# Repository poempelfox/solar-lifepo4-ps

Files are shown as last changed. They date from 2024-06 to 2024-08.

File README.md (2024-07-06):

# Solar-LiFePO4 power-supply module

## Intro

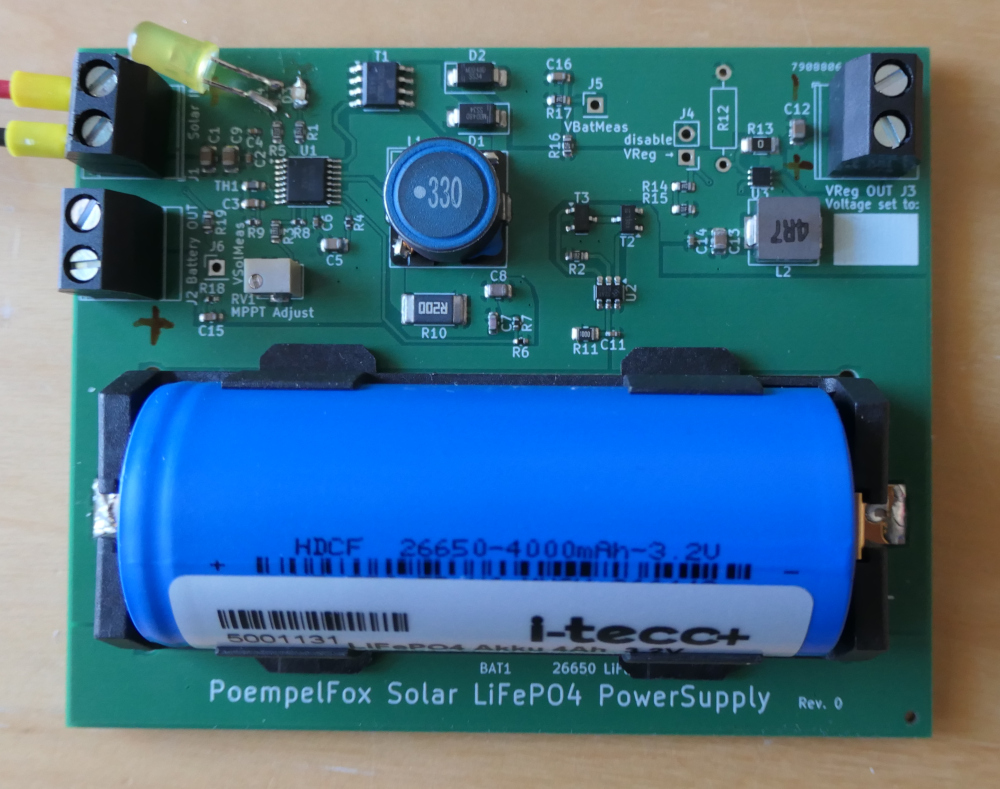
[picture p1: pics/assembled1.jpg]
picture showing the first revision of the board in this project. A printed circuit board with many components mounted on, including a very big battery covering almost the bottom half of the picture.


The goal of this project is to build a power-supply
module with a standard 26650 LiFePO4 battery that can
be powered from a small solar panel and will take
care of all the handling of the battery, including
protection, for you.
The battery is put into a battery holder that is
directly on the board.

Essentially, this is trying to build something
very similiar to Waveshares "Solar Power Manager",
just using LiFePO4 instead of Li-Ion. The
downside is the smaller energy density. The upside
is that LiFePO4 is much much more stable and simply
can not spontanously burst into flames.

I would have preferred to not design this myself,
because I'm really out of my depth here. However,
I was completely unable to find something ready-made
to buy, and even my search for (open-source-)projects
that had already built something like that proved
fruitless. Of course, after I was two-thirds finished,
I accidently found the
[LiFePO4 Solar Charger by Stefan Wagner](https://github.com/wagiminator/Power-Boards/blob/master/Solar_Charger/readme.md)
that would have been almost exactly what I was looking
for, but by then it was too late.

During construction,
[a blog entry by Malte Poeggel and his design files](https://www.maltepoeggel.de/?site=solar-mppt-cn3722&lang=en)
was a great inspiration, because it uses the same
main charge controller (CN3722) and so I had a known-working
design to start from.

## Features

Input is meant to be a 12V solar panel. Maximum input
voltage for the circuit is 25V, so the solar panel
voltage without any load should be fine.

The board has a slot for a standard 26650 LiFePO4
flat top unprotected battery. The protection circuit
(HY2112) is on the board and protects against
short circuits, overcharge, and deep discharge.
There is also protection against charging below
0°C (which can damage LiFePO4 batteries), but that
is done by the main CN3722 charge controller which has
a Thermistor connected for that purpose. Note that
because the Thermistor is on the board and not
directly attached to the battery, this may be
insufficient for some use cases where large
temperature differences between board and battery
can occour.

Charge current is capped at 1A.

There is a regulated 5V output through an ultra-
efficient MAX17224 boost converter. Output voltage can
be reconfigured to between 3.4 - 5V by removing and
soldering in another resistor. However, because this
is a boost converter, you cannot (reliably) go below
3.4V - the minimum voltage is (battery voltage - 0.2V).
You should be able to pull around 400 mA at 5V or
600 mA at 3.4V out of this - although if you pull this
much current permanently, you'll not last long
with such a small battery.

You can also get the 3.0V - 3.6V output coming from
the battery directly, but that is of course completely
unregulated, and will fluctuate as the battery charges
and discharges. This output is behind the battery
protection circuit, so protected against deep
discharge.

There is a jumper for disabling the boost converter
completely if you don't need the regulated output.
It's also possible to connect a microcontroller to
that jumper and thereby enable/disable the regulated
output in software. A nifty feature of the MAX17224
is that when it is disabled, it completely disconnects
its output, meaning it doesn't care at all if you
feed voltage into that.

Finally, there are two voltage dividers on the board,
with an output that is intended to be connected to
an ADC pin of a microcontroller. A 10 MOhm / 1 MOhm
divider to measure the voltage coming from the solar
panel, and a 10 MOhm / 10 MOhm divider for the battery
voltage. These were selected so that the output
conveniently matches the range of your standard ESP32.

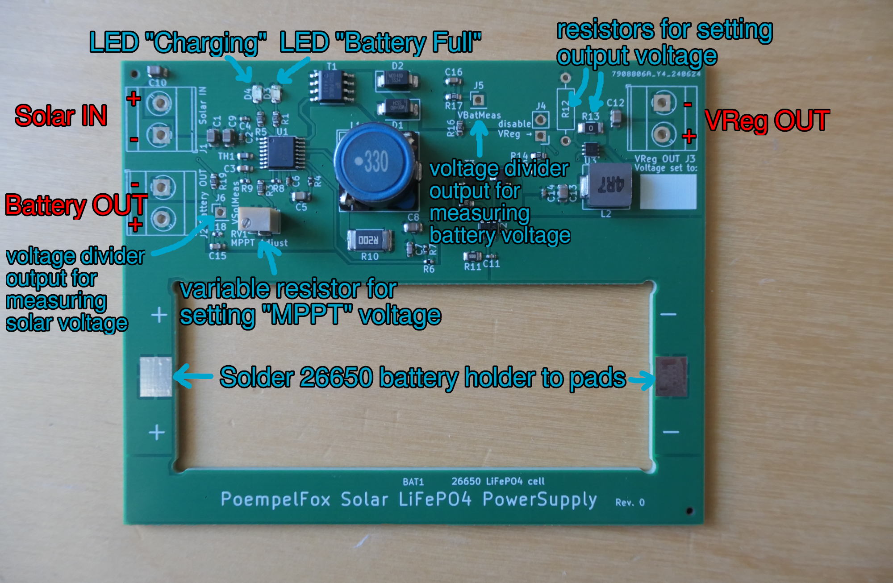
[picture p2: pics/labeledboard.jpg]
a picture showing the printed circuit board, with labels showing what needs to be connected where.


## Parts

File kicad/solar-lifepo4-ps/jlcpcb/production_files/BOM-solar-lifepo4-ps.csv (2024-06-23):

Comment | Designator | Footprint | LCSC
C1 | 22uF | C_0805_2012Metric | C45783 | 4372673 | 0 | 0
C10 | 22uF | C_0805_2012Metric | C45783 | 4372673 | 0 | 0
C11 | 100nF | C_0402_1005Metric | C307331 | 6856879 | 0 | 0
C12 | 22uF | C_0805_2012Metric | C45783 | 4372673 | 0 | 0
C13 | 22uF | C_0805_2012Metric | C45783 | 4372673 | 0 | 0
C14 | 100nF | C_0402_1005Metric | C307331 | 6856879 | 0 | 0
C15 | 1nF | C_0603_1608Metric | C1588 | 6040604 | 0 | 0
C16 | 1nF | C_0603_1608Metric | C1588 | 6040604 | 0 | 0
C2 | 100nF | C_0402_1005Metric | C307331 | 6856879 | 0 | 0
C3 | 470pF | C_0603_1608Metric | C1620 | 841712 | 0 | 0
C4 | 100nF | C_0402_1005Metric | C307331 | 6856879 | 0 | 0
C5 | 220nF | C_0805_2012Metric | C5378 | 425353 | 0 | 0
C6 | 100nF | C_0402_1005Metric | C307331 | 6856879 | 0 | 0
C7 | 18pF | C_0603_1608Metric | C1647 | 224429 | 0 | 0
C8 | 10uF | C_0805_2012Metric | C15850 | 2210217 | 0 | 0
C9 | 22uF | C_0805_2012Metric | C45783 | 4372673 | 0 | 0
D1 | SS34 | D_SMA | C8678 | 997276 | 0 | 0
D2 | SS34 | D_SMA | C8678 | 997276 | 0 | 0
D3 | LED green | R_0805_2012Metric | C2297 | 1323534 | 0 | 0
D4 | LED yellow | R_0805_2012Metric | C2296 | 258402 | 0 | 0
L1 | 33uH | L_TDK_SLF12575 | C87568 | 2465 | 0 | 0
L2 | 4.7uH | L_Sunlord_MWSA0603S | C408447 | 60265 | 0 | 0
R1 | 2.4k | R_0603_1608Metric | C22940 | 702809 | 0 | 0
R10 | 200m | R_2512_6332Metric | C5375488 | 8341 | 0 | 0
R11 | 100 | R_0805_2012Metric | C17408 | 6372890 | 0 | 0
R13 | VoltageSelB | R_1206_3216Metric | C17888 | 8173888 | 0 | 0
R14 | 10M | R_0603_1608Metric | C7250 | 225082 | 0 | 0
R15 | 10M | R_0603_1608Metric | C7250 | 225082 | 0 | 0
R16 | 10M | R_0603_1608Metric | C7250 | 225082 | 0 | 0
R17 | 10M | R_0603_1608Metric | C7250 | 225082 | 0 | 0
R18 | 1M | R_0402_1005Metric | C26083 | 2594408 | 0 | 0
R19 | 10M | R_0603_1608Metric | C7250 | 225082 | 0 | 0
R2 | 1.8k | R_0603_1608Metric | C4177 | 435015 | 0 | 0
R3 | 3.9k | R_0603_1608Metric | C23018 | 817563 | 0 | 0
R4 | 120 | R_0402_1005Metric | C25079 | 547006 | 0 | 0
R5 | 2.4k | R_0603_1608Metric | C22940 | 702809 | 0 | 0
R6 | 48.7k | R_0402_1005Metric | C103068 | 47167 | 0 | 0
R7 | 23.7k | R_0402_1005Metric | C82134 | 14674 | 0 | 0
R8 | 100k | R_0402_1005Metric | C25741 | 4991595 | 0 | 0
R9 | 1M | R_0402_1005Metric | C26083 | 2594408 | 0 | 0
RV1 | Poti 10k | Potentiometer_Bourns_3224W_Vertical | C81348 | 6722 | 0 | 0
T1 | SI4435DY | SOP-8_3.9x4.9mm_P1.27mm | C4355022 | 19004 | 0 | 0
T2 | AO3400A | SOT-23 | C20917 | 628525 | 0 | 0
T3 | AO3400A | SOT-23 | C20917 | 628525 | 0 | 0
TH1 | Thermistor NTC 10k | R_0603_1608Metric | C13564 | 438964 | 0 | 0
U1 | CN3722 | TSSOP-16_4.4x5mm_P0.65mm | C77905 | 5126 | 0 | 0
U2 | HY2112 | SOT-23-6 | C168763 | 5680 | 0 | 0
U3 | MAX17224ELT+T | UDFN-6_L2.0-W2.0-P0.65-BL-1 | C2683469 | 139 | 0 | 0

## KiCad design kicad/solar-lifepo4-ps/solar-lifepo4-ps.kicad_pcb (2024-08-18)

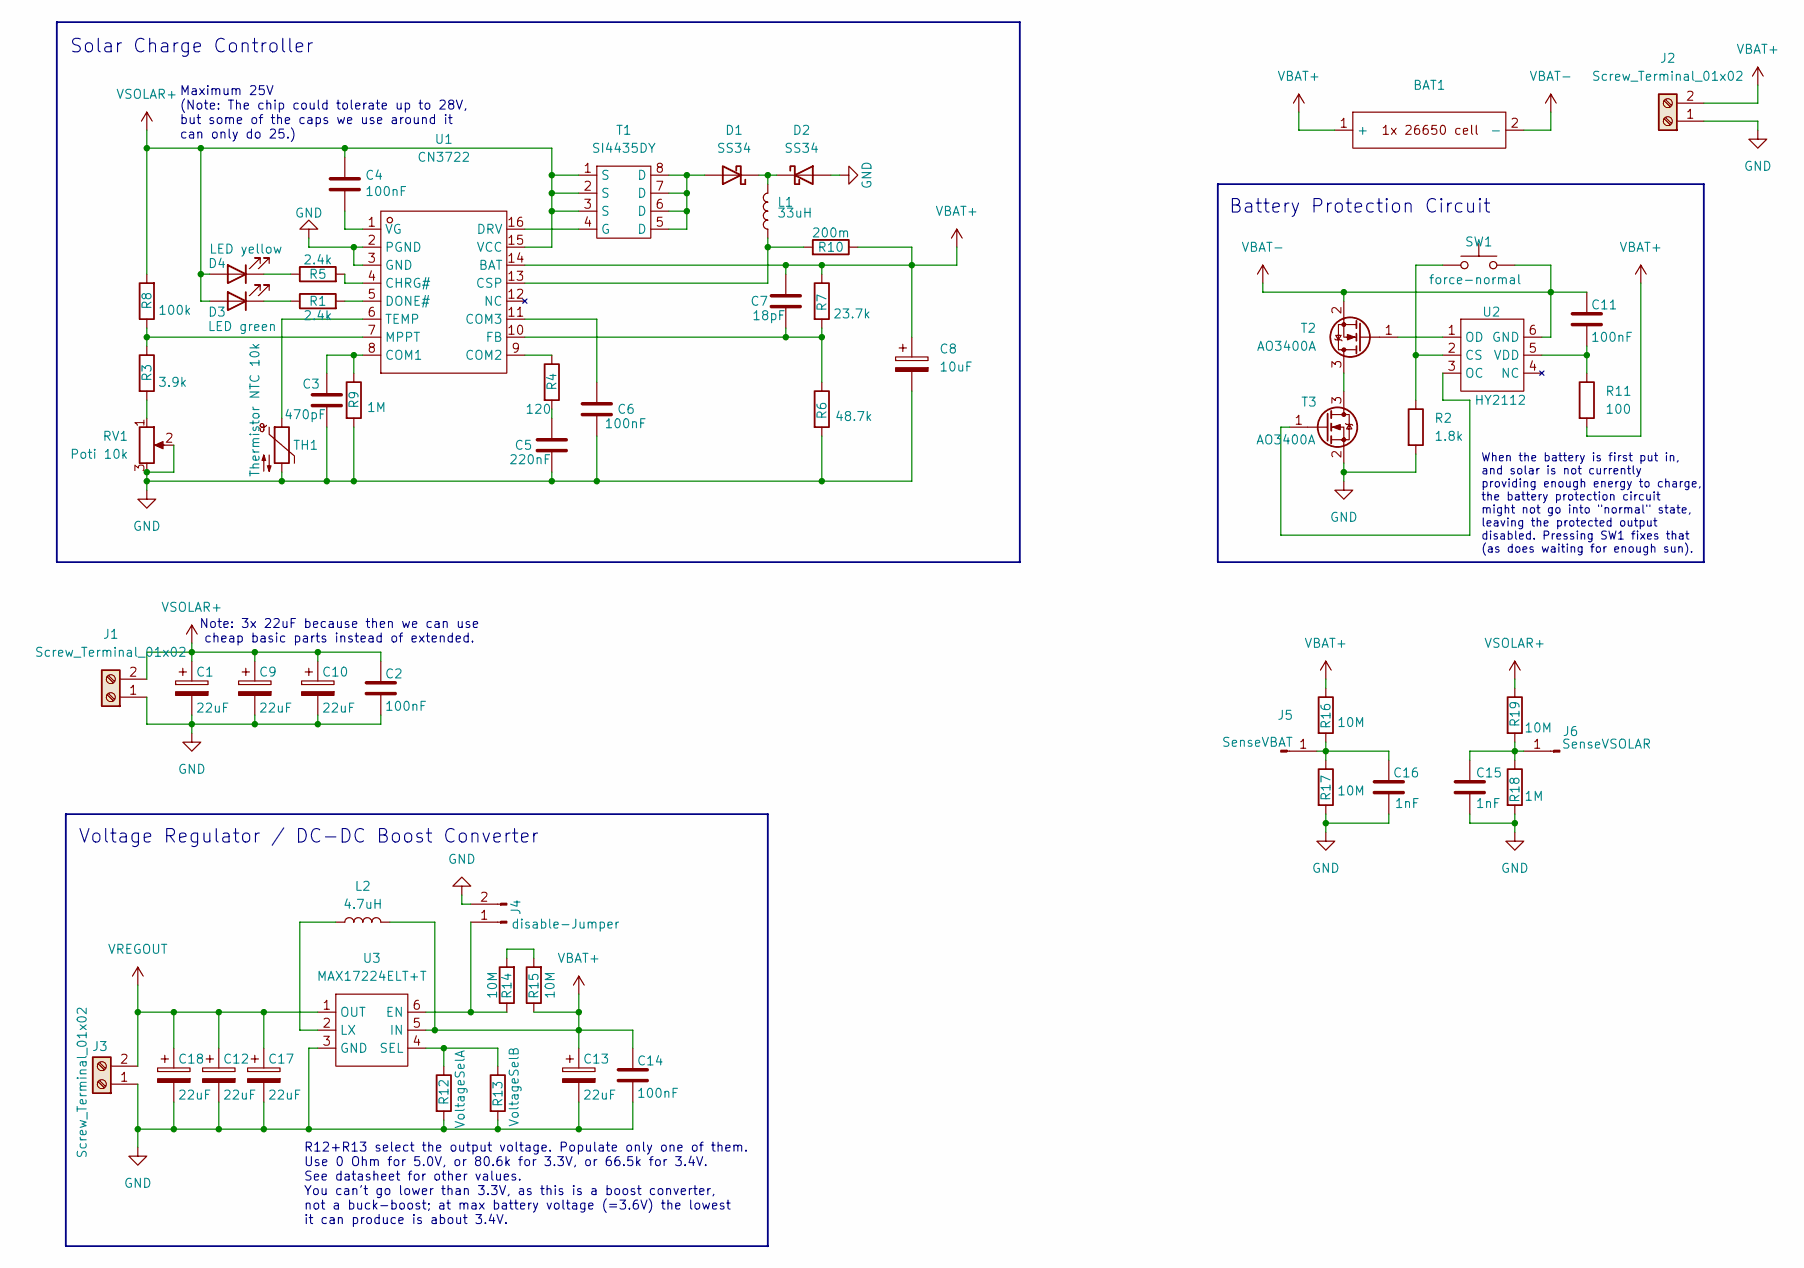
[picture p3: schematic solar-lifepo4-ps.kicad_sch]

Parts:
BAT1: batteryholder_keystone_1106-jlcpcb
C1, C9, C10, C12, C13, C17, C18: 22uF; C_0805_2012Metric
C2, C4, C6, C11, C14: 100nF; C_0402_1005Metric
C3: 470pF; C_0603_1608Metric
C5: 220nF; C_0805_2012Metric
C7: 18pF; C_0603_1608Metric
C8: 10uF; C_0805_2012Metric
C15, C16: 1nF; C_0603_1608Metric
D1, D2: SS34; D_SMA
D3: LED green; LED_0805_2012Metric
D4: LED yellow; LED_0805_2012Metric
J1, J2, J3: Screw_Terminal_01x02; TerminalBlock_MetzConnect_Type073_RT02602HBLU_1x02_P5.08mm_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
J4: disable-Jumper; PinHeader_1x02_P2.54mm_Vertical
J5: SenseVBAT; PinHeader_1x01_P2.54mm_Vertical
J6: SenseVSOLAR; PinHeader_1x01_P2.54mm_Vertical
L1: 33uH; L_TDK_SLF12575
L2: 4.7uH; L_Sunlord_MWSA0603S
R1, R5: 2.4k; R_0603_1608Metric
R2: 1.8k; R_0603_1608Metric
R3: 3.9k; R_0603_1608Metric
R4: 120; R_0402_1005Metric
R6: 48.7k; R_0402_1005Metric
R7: 23.7k; R_0402_1005Metric
R8: 100k; R_0402_1005Metric
R9, R18: 1M; R_0402_1005Metric
R10: 200m; R_2512_6332Metric
R11: 100; R_0805_2012Metric
R12: VoltageSelA; R_Axial_DIN0207_L6.3mm_D2.5mm_P10.16mm_Horizontal
R13: VoltageSelB; R_1206_3216Metric
R14, R15, R16, R17, R19: 10M; R_0603_1608Metric
RV1: Poti 10k; Potentiometer_Bourns_3224W_Vertical
SW1: force-normal; SW_Push_1P1T_XKB_TS-1187A
T1: SI4435DY; SOP-8_3.9x4.9mm_P1.27mm
T2, T3: AO3400A; SOT-23
TH1: Thermistor NTC 10k; R_0603_1608Metric
U1: CN3722; TSSOP-16_4.4x5mm_P0.65mm
U2: HY2112; SOT-23-6
U3: MAX17224ELT+T; UDFN-6_L2.0-W2.0-P0.65-BL-1

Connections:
GND: C1.2, C2.2, C3.2, C5.2, C6.2, C8.2, C9.2, C10.2, C12.2, C13.2, C14.2, C15.2, C16.2, C17.2, C18.2, D2.2 (A), J1.1, J2.1, J3.1, J4.2, R2.2, R6.2, R9.2, R12.2, R13.2, R17.2, R18.2, RV1.2, RV1.3, T3.2 (S), TH1.2, U1.2 (PGND), U1.3 (GND), U3.3 (GND)
unnamed: C5.1, R4.2
unnamed: D1.2 (A), T1.5 (D), T1.6 (D), T1.7 (D), T1.8 (D)
unnamed: D1.1 (K), D2.1 (K), L1.2
unnamed: D3.1 (K), R1.1
unnamed: D4.1 (K), R5.1
unnamed: J4.1, R14.1, U3.6 (EN)
unnamed: C16.1, J5.1, R16.2, R17.1
unnamed: C15.1, J6.1, R18.1, R19.2
unnamed: R3.2, RV1.1
unnamed: R14.2, R15.2
unnamed: T1.4 (G), U1.16 (DRV)
unnamed: T2.3 (D), T3.3 (D)
unnamed: T2.1 (G), U2.1 (OD)
unnamed: T3.1 (G), U2.3 (OC)
unnamed: R5.2, U1.4 (CHRG#)
unnamed: C3.1, R9.1, U1.8 (COM1)
unnamed: R4.1, U1.9 (COM2)
unnamed: C6.1, U1.11 (COM3)
unnamed: L1.1, R10.2, U1.13 (CSP)
unnamed: R1.2, U1.5 (DONE#)
unnamed: C7.2, R6.1, R7.2, U1.10 (FB)
unnamed: R3.1, R8.1, U1.7 (MPPT)
unnamed: TH1.1, U1.6 (TEMP)
unnamed: C4.1, U1.1 (VG)
unnamed: R2.1, SW1.1, U2.2 (CS)
unnamed: C11.2, R11.1, U2.5 (VDD)
unnamed: L2.1, U3.2 (LX)
unnamed: R12.1, R13.1, U3.4 (SEL)
VBAT+: BAT1.1 (+), C7.1, C8.1, C13.1, C14.1, J2.2, L2.2, R7.1, R10.1, R11.2, R15.1, R16.1, U1.14 (BAT), U3.5 (IN)
VBAT-: BAT1.2 (-), C11.1, SW1.2, T2.2 (S), U2.6 (GND)
VREGOUT: C12.1, C17.1, C18.1, J3.2, U3.1 (OUT)
VSOLAR+: C1.1, C2.1, C4.2, C9.1, C10.1, D3.2 (A), D4.2 (A), J1.2, R8.2, R19.1, T1.1 (S), T1.2 (S), T1.3 (S), U1.15 (VCC)

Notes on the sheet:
Solar Charge Controller
Maximum 25V (Note: The chip could tolerate up to 28V, but some of the caps we use around it can only do 25.)
Voltage Regulator / DC-DC Boost Converter
Note: 3x 22uF because then we can use cheap basic parts instead of extended.
R12+R13 select the output voltage. Populate only one of them. Use 0 Ohm for 5.0V, or 80.6k for 3.3V, or 66.5k for 3.4V. See datasheet for other values. You can't go lower than 3.3V, as this is a boost converter, not a buck-boost; at max battery voltage (=3.6V) the lowest it can produce is about 3.4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
Battery Protection Circuit
When the battery is first put in, and solar is not currently providing enough energy to charge, the battery protection circuit might not go into "normal" state, leaving the protected output disabled. Pressing SW1 fixes that (as does waiting for enough sun).

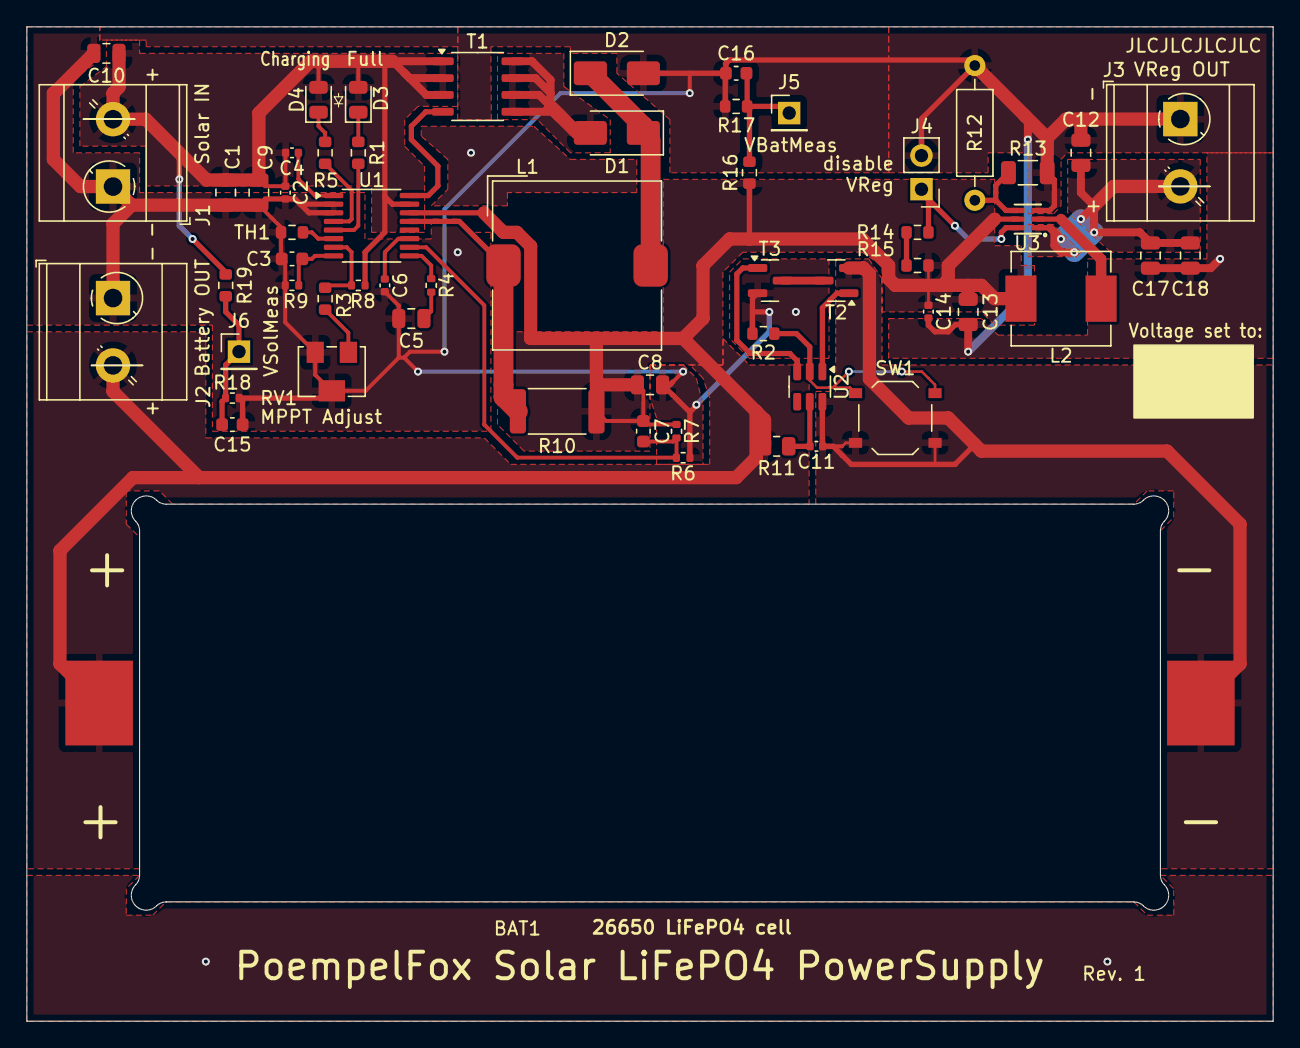
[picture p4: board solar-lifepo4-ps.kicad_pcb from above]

Board: 2 copper layers, 94.0 x 75.0 mm, 59 parts (0 on the bottom side), 33 nets.

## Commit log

2024-06-18 initial commit - what we produced since saturday.
    [solar-lifepo4-ps.kicad_pcb, solar-lifepo4-ps.kicad_sch]
2024-06-21 still WIP
    [solar-lifepo4-ps.kicad_pcb, solar-lifepo4-ps.kicad_sch]
2024-06-22 current state. All the main circuit has been designed now. TODO: voltage divider output to permit a connected MC to measure voltages; fix square hole in PCB because JLCPCB will not be able to manufac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
    [solar-lifepo4-ps.kicad_pcb, solar-lifepo4-ps.kicad_sch]
2024-06-23 rev 0, as it was sent to jlcpcb for production.
    [BOM-solar-lifepo4-ps.csv, solar-lifepo4-ps.kicad_pcb, solar-lifepo4-ps.kicad_sch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]
2024-07-04 first few fixes after Rev. 0 arrived from the JLCPCB-fab. It seems to be mostly working fine, but I made a few small errors - like forgetting the labels for +/- and using resistor-footprints for the 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
    [solar-lifepo4-ps.kicad_pcb, solar-lifepo4-ps.kicad_sch]
2024-07-06 more labeling on the silkscreen, minor ground plane movement.
    [solar-lifepo4-ps.kicad_pcb, solar-lifepo4-ps.kicad_sch]
2024-07-06 move label so it's not partially hidden by the battery holder when soldered on.
    [solar-lifepo4-ps.kicad_pcb]
2024-07-07 add pushbutton to force the battery protection circuit into "normal" mode. When a battery is inserted, but there is not and has never been enough power to actually charge, the battery protection circ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
    [solar-lifepo4-ps.kicad_pcb, solar-lifepo4-ps.kicad_sch]
2024-08-17 add more capacitors at the output of the voltage converter because as it turns out, 1x 22uF was just NOT enough. So we now have 3x 22uF instead.
    [solar-lifepo4-ps.kicad_pcb, solar-lifepo4-ps.kicad_sch]
2024-08-18 do not route traces below the inductor
    [solar-lifepo4-ps.kicad_pcb]
